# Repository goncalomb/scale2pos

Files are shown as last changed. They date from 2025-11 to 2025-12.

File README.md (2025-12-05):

# Scale 2 POS (scale2pos)

The goal of this project is to connect a [retail scale](https://duckduckgo.com/?q=retail+scale) to a [POS (point-of-sale) system](https://duckduckgo.com/?q=pos+system) using 2 Raspberry Pi Pico W.

The scale has an RS-232 port that is normally connected directly to the POS, but in this case it is connected to an RPi that reads the weight from the scale and transmits it to the other RPi (over Wi-Fi), the second RPi inputs the weight (and product code) on the POS. This removes the need for the scale and POS to be physically connected.

> This is a very specific project to solve a very specific problem. I don't expect it to be useful to anyone as is, but it has some components that can be used on other projects:
>
> - [mpy-ctrl.sh](mpy-ctrl.sh): a bash script to setup and manage any MicroPython project;
> - [src/utils/](src/utils/): generic MicroPython utilities ([net.py](src/utils/net.py) is a nice one);
> - [3D Models](#3d-models-for-3d-printing): project box models for 3D printing;
>
> This was my first project in MicroPython and served as my introduction to the platform. &mdash;goncalomb

## Images

Final device images ([images/](images/)):

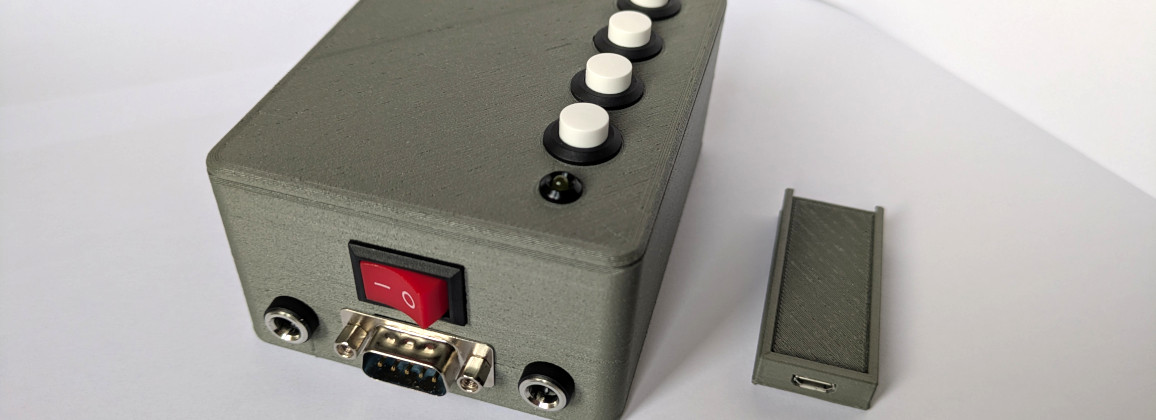
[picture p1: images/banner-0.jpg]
banner-0


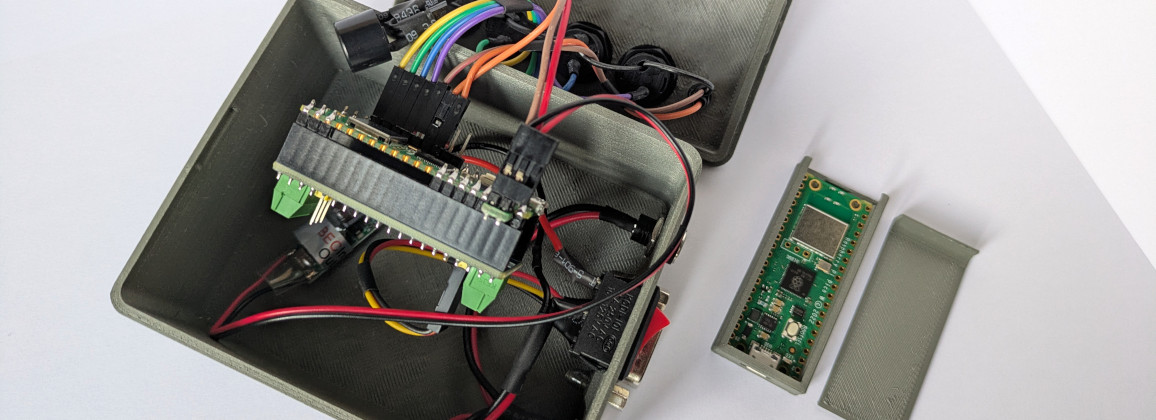
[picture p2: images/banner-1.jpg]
banner-1


## Requirements / Setup

"Client" RPi (scale):

- Connects to the scale using RS-232;
- Connects to the "server" using Wi-Fi;
- Powered by 12V (shared with the scale, 2.1mm jack);
- Has a buzzer for audio feedback;
- Has a set of push buttons for different product codes;
- Reads the weight from the scale and transmits it to the "server" (Web API), together with the product code as a barcode with embedded weight;

"Server" RPi (POS):

- Connects to the POS using USB;
- Acts as a USB keyboard;
- Acts as a Wi-Fi access point and web server (HTTP);
- Receives and emulates keyboard codes, the POS interprets these inputs as barcodes and registers the product;

## Hardware

This is a non-exhaustive list, there is no custom PCB or schematic:

- 2x [Raspberry Pi Pico W](https://www.raspberrypi.com/documentation/microcontrollers/pico-series.html);
- 1x [Waveshare Pico-2CH-RS232](https://www.waveshare.com/wiki/Pico-2CH-RS232);
- 2.1mm panel jacks, power switch, diode (1N4007), UBEC (5V/3A);
- 3V buzzer (TMB12A03), transistor (2N3904), resistor (1k);
- Yellow LED, resistor (1k);
- Generic push buttons, wires, etc.;

> You may have noticed in the images that I've connected the 3V buzzer to 5V! Oops, that was not intentional. According to the datasheet, 5V is the operating voltage limit for this buzzer. If it fails (I don't think it will), I'll change it to a 5V buzzer. &mdash;goncalomb

## Software (MicroPython)

The code is shared between the "client" and "server", it is managed and installed using the custom `mpy-ctrl.sh` script. The variant is selected when pushing the code:

```bash
# setup environment and download dependencies
./mpy-ctrl.sh setup

# install the "client" variant (scale)
./mpy-ctrl.sh push client

# install the "server" variant (POS)
./mpy-ctrl.sh push server

# install the "serial-debug" variant (interactive serial debug console)
./mpy-ctrl.sh push serial-debug
```

## 3D Models (for 3D printing)

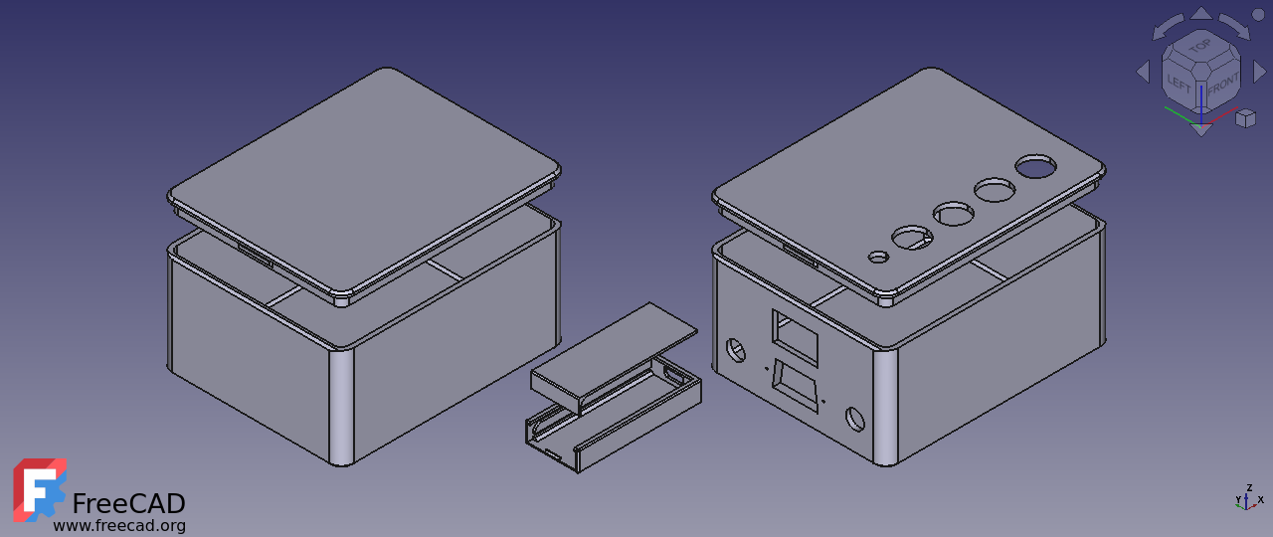
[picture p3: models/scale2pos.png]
scale2pos


Project box models for 3D printing ([models/](models/)). The "Pico Box" (in the middle) is for the "server" that connects with the POS. The big box is for the "client" that connects with the scale.

> You may use these models for your own projects!
>
> The "Pico Box" (also [published on printables](https://www.printables.com/model/1504252-pico-box)) is just a plain box that fits the Raspberry Pi Pico perfectly with no screws. The big box can used as a generic project box.
>
> The parametric FreeCAD project is also available ([models/scale2pos.FCStd](models/scale2pos.FCStd)). License: [CC BY-SA 4.0](https://creativecommons.org/licenses/by-sa/4.0/).
>
> I'm still learning FreeCAD, these are my first published models. &mdash;goncalomb

## References

Reference documents ([references/](references/)), most important:

- [tw-vw-protocols-v5.pdf](references/tw-vw-protocols-v5.pdf): retail scale serial protocols (Baxtran);
- [Standard-GS1-PT-Codificacao-Produtos-Peso-Variavel.pdf](references/Standard-GS1-PT-Codificacao-Produtos-Peso-Variavel.pdf): variable weight barcode format (in Portuguese);

## License

### 3D Models

Creative Commons license: [CC Attribution-ShareAlike 4.0](https://creativecommons.org/licenses/by-sa/4.0/).

### Software

scale2pos is released under the terms of the MIT License. See [LICENSE.txt](LICENSE.txt) for details.

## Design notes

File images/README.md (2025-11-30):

# Images

banner-0

banner-1

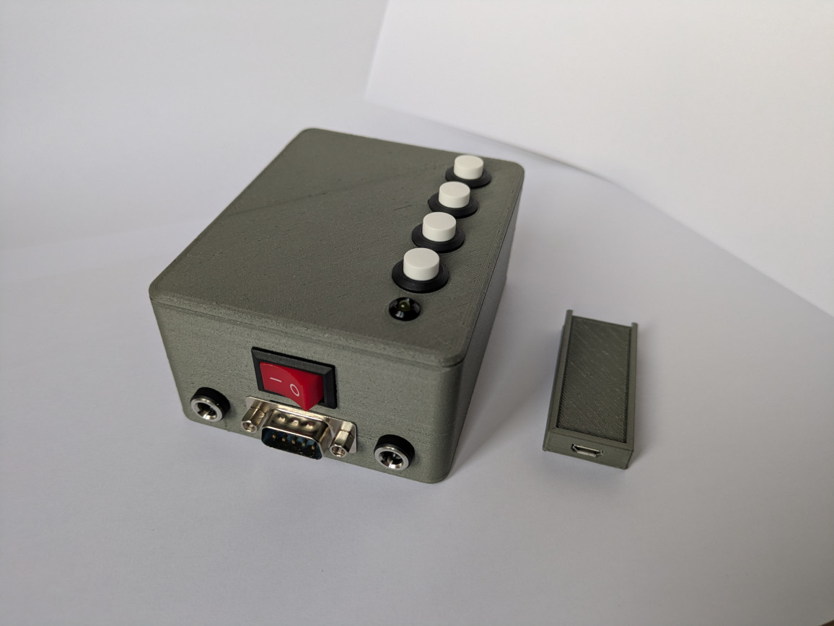
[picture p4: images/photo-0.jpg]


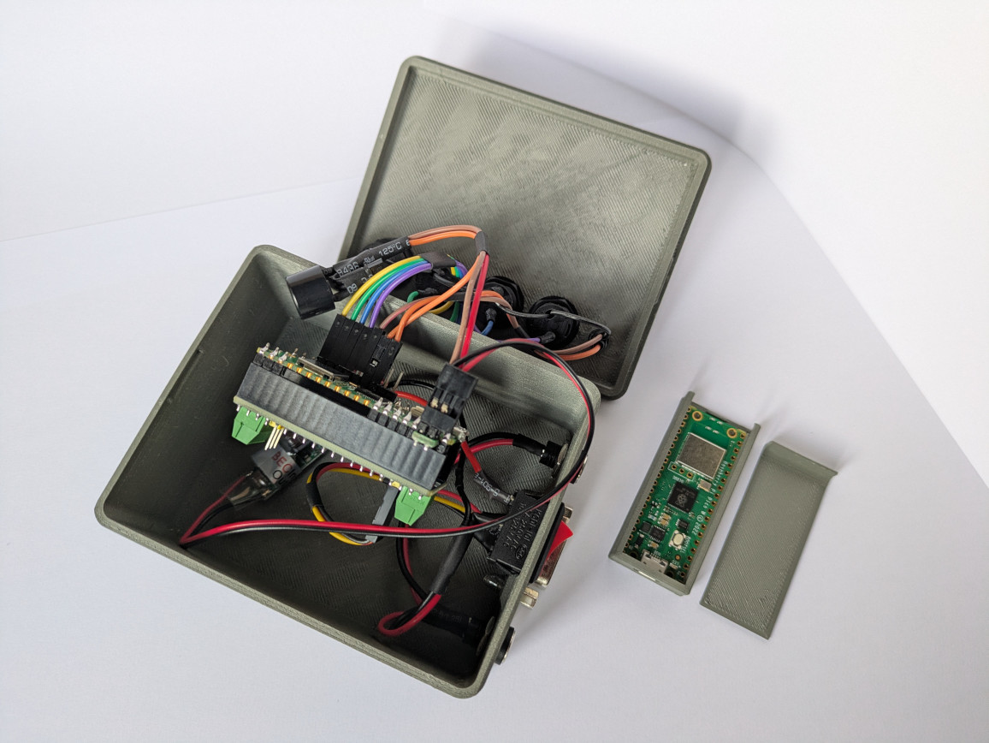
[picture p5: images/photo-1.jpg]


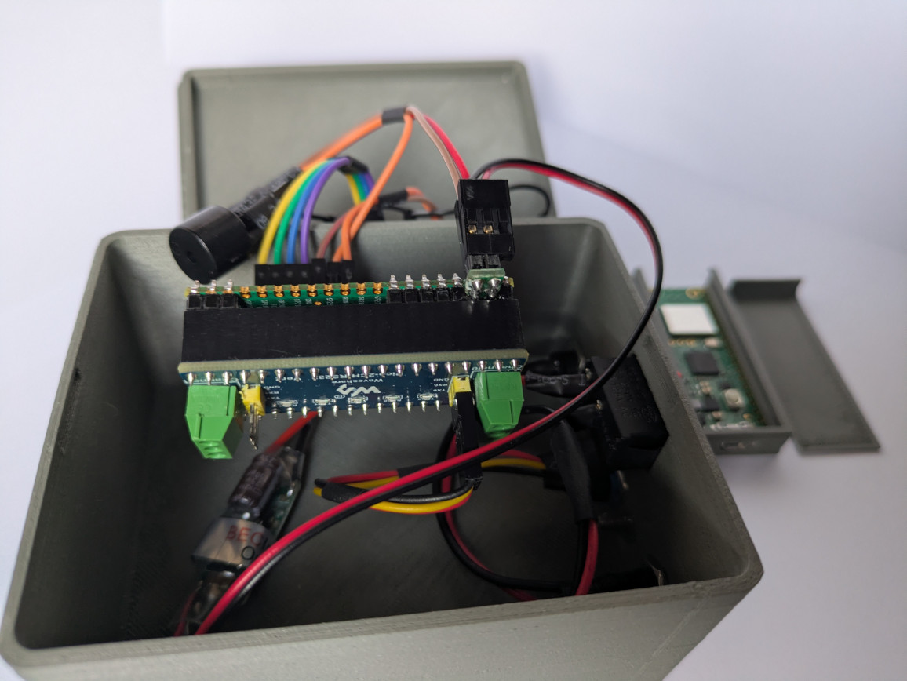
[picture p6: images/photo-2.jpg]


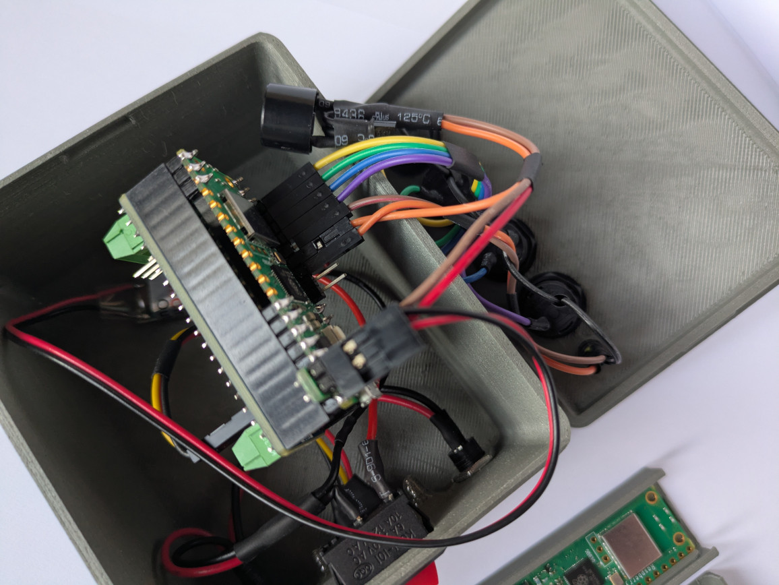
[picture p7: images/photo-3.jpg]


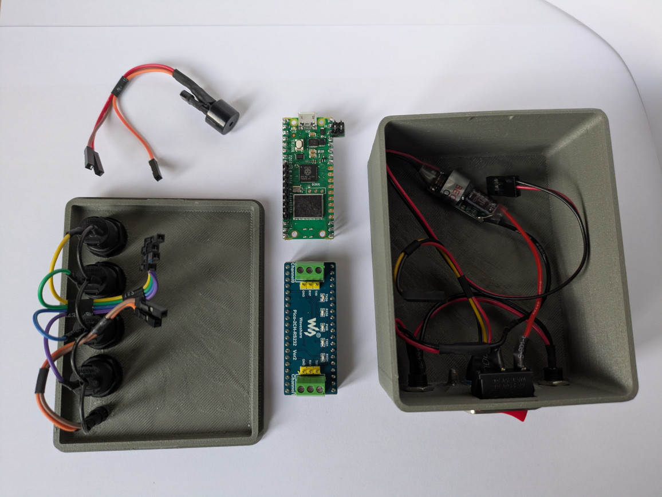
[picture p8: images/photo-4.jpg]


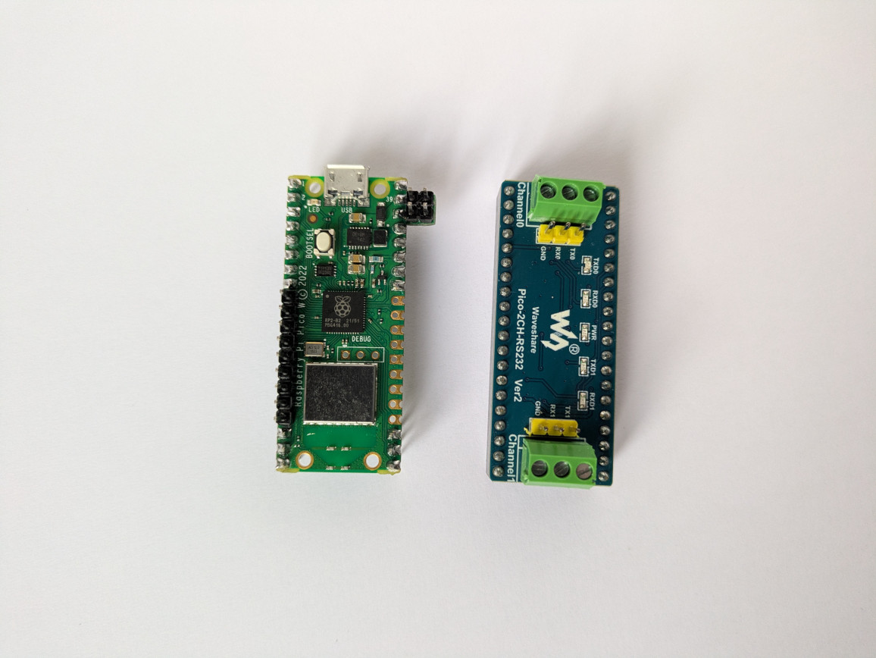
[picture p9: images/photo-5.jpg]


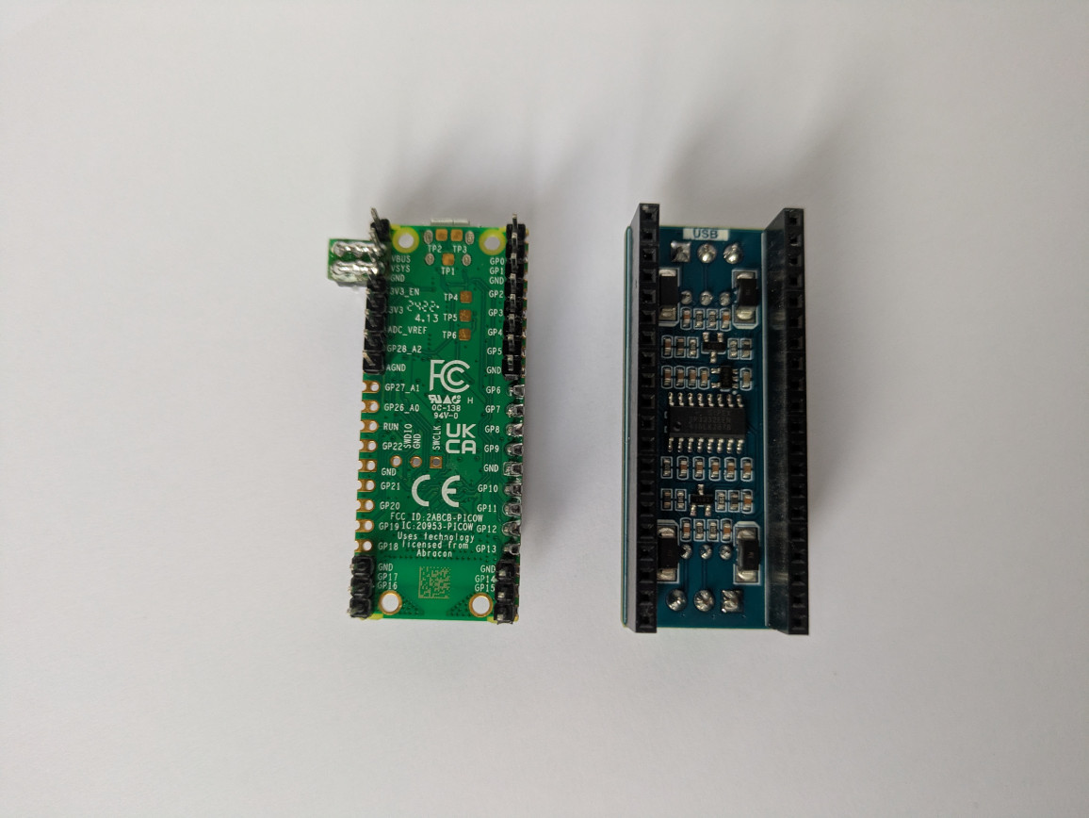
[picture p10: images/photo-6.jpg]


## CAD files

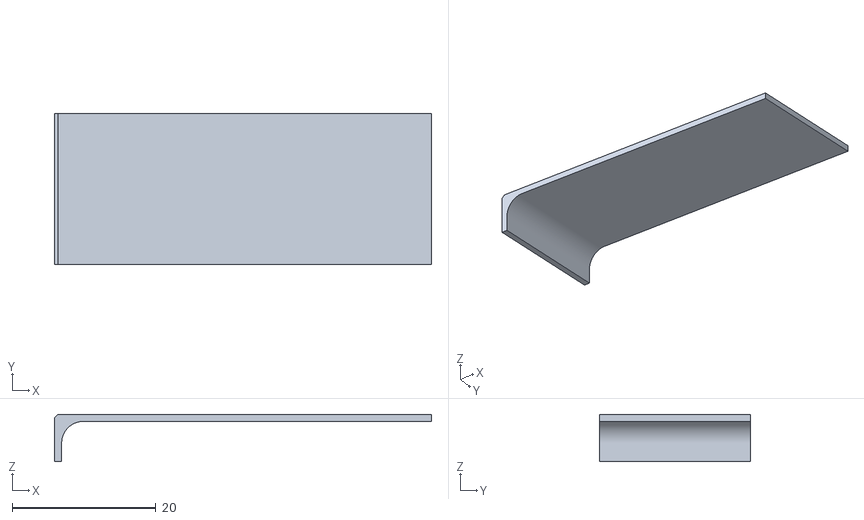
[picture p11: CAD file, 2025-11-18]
models/scale2pos-PicoLid.stl
52.4 x 21.0 x 6.60

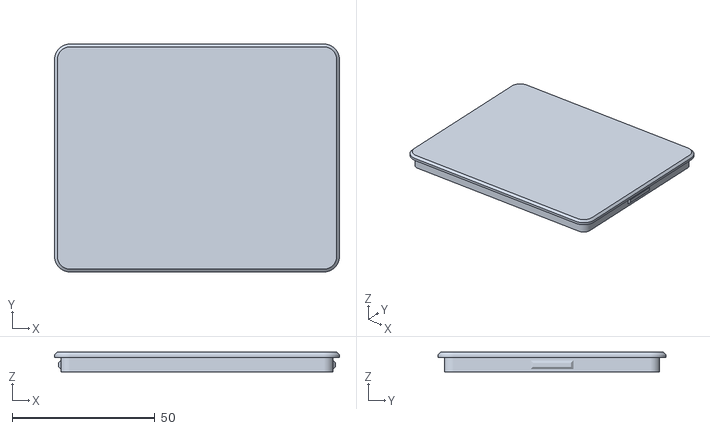
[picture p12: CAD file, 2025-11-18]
models/scale2pos-Lid.stl
100.0 x 80.0 x 7.00

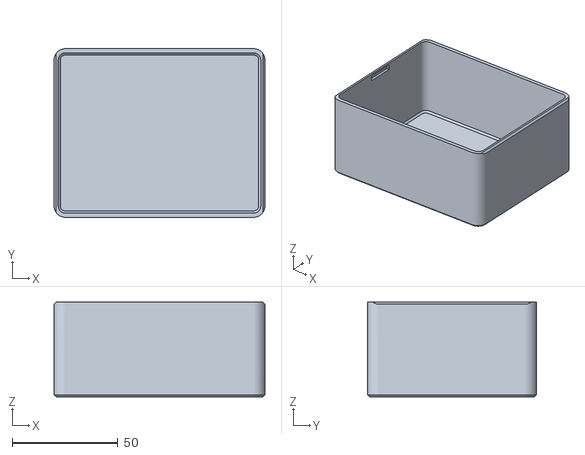
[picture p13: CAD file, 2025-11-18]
models/scale2pos-Box.stl
100.0 x 80.0 x 45.0

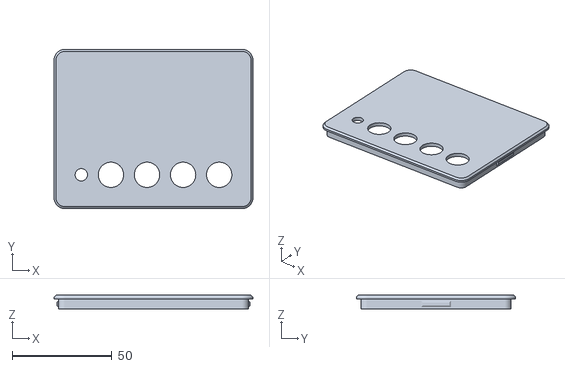
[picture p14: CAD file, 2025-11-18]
models/scale2pos-LidFinal.stl
100.0 x 80.0 x 7.00

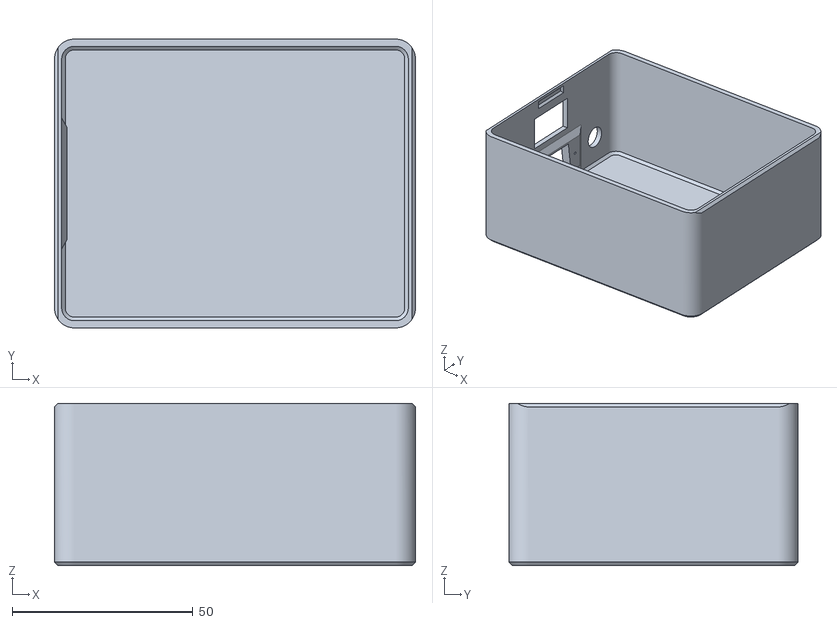
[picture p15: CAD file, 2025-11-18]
models/scale2pos-BoxFinal.stl
100.0 x 80.0 x 45.0

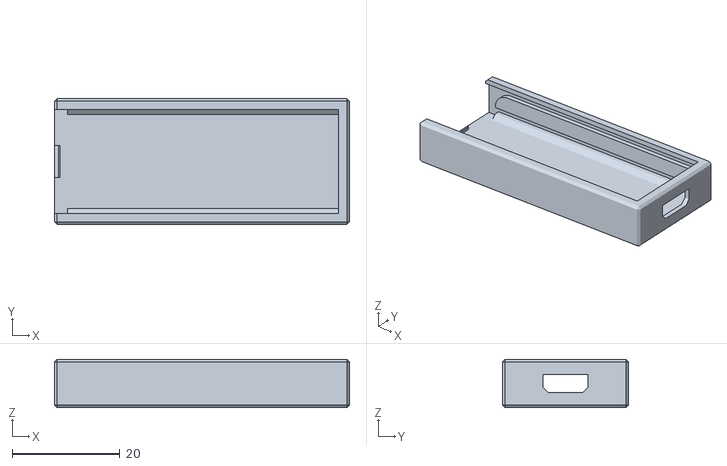
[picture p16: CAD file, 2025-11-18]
models/scale2pos-PicoBox.stl
54.8 x 23.4 x 9.00

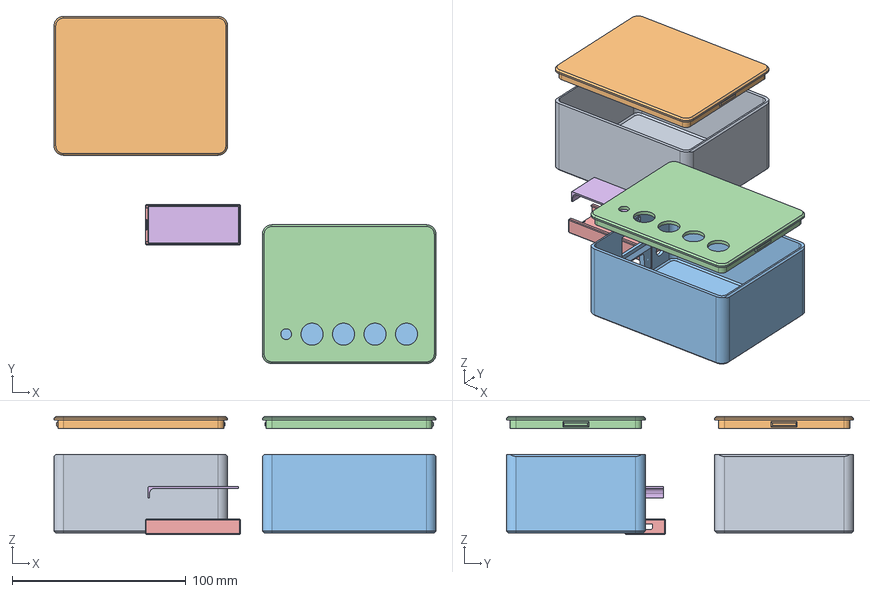
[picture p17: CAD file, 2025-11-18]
models/scale2pos.FCStd
220.0 x 200.0 x 68.0 mm
Lid
BoxFinal
LidFinal
PicoBox
PicoLid

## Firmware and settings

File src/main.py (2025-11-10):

from mpy_ctrl import args

from utils.bootstrap import panic, run
from utils.keyboard import keyboard_setup

variant = args[0] if args and args[0] in [
    'client', 'server', 'serial-debug',
] else None
if not variant:
    panic('invalid variant')

if variant == 'server':
    # do keyboard setup as early as possible
    keyboard_setup()

if variant == 'client':
    from utils.led import led_setup
    from config import scale_gpio_led
    led_setup(scale_gpio_led)


async def main():
    # defer app import
    if variant == 'serial-debug':
        from utils.serial import serial_debug_start
        await serial_debug_start()
    else:
        from app import start
        await start(variant == 'server')

run(main())

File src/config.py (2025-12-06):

import config_gen

wlan_ssid = 'SCALE2POS_' + config_gen.wlan_ssid_suffix
wlan_key = config_gen.wlan_key

gpio_buzzer = 9
led_error_state_flash = 150  # (X * 400ms) = 60000ms = 60s

pos_keyboard_code_max = 20
pos_keyboard_delay = 20
pos_keyboard_delay_max = 500
pos_keyboard_delay_long = 750
pos_keyboard_delay_long_max = 1500

scale_gpio_led = 8
scale_serial_phys = (0, 0, 1)  # id, tx, rx,
scale_serial_proto = (9600, 8, None, 1)  # speed, bits, parity, stop
scale_serial_extra_tx = 4  # extra unused tx pin to pull up (dual transceiver)
scale_code_prefix = '>>_'  # send ENTER twice to bust the screensaver
scale_gpio_reset = 10  # must be one of the product buttons (long press)
scale_gpio_product_codes = {  # product buttons (short press)
    10: '10010',
    11: '10011',
    12: '10012',
    13: '10013',
}

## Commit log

2025-10-21 Add utility to control LED state
2025-10-25 Add gpio utility with button polling task
2025-10-25 Add reset after asyncio loop ends
    [bootstrap.py]
2025-10-30 Add core logic (handle buttons, buzzer and sending weight codes)
    [app.py, config.py, gpio.py]
2025-11-10 Add configuration for status LED
2025-11-18 Add 3D models
    [scale2pos-Box.stl, scale2pos-BoxFinal.stl, scale2pos-Lid.stl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]
2025-11-22 Fix button concurrency issue (not waiting for buzzer)
    [app.py, gpio.py]
2025-11-22 Add config to limit LED error state flash
    [app.py, config.py]
